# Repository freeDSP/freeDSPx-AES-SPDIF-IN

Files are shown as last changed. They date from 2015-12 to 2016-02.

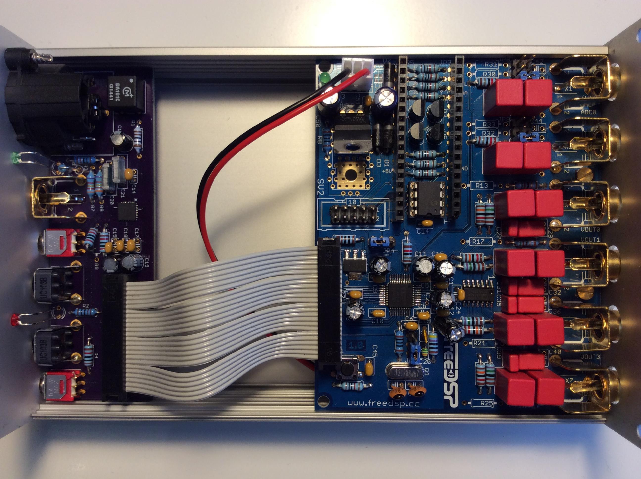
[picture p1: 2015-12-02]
DOCUMENTATION/PICTURES/Assembled V1.1.jpg

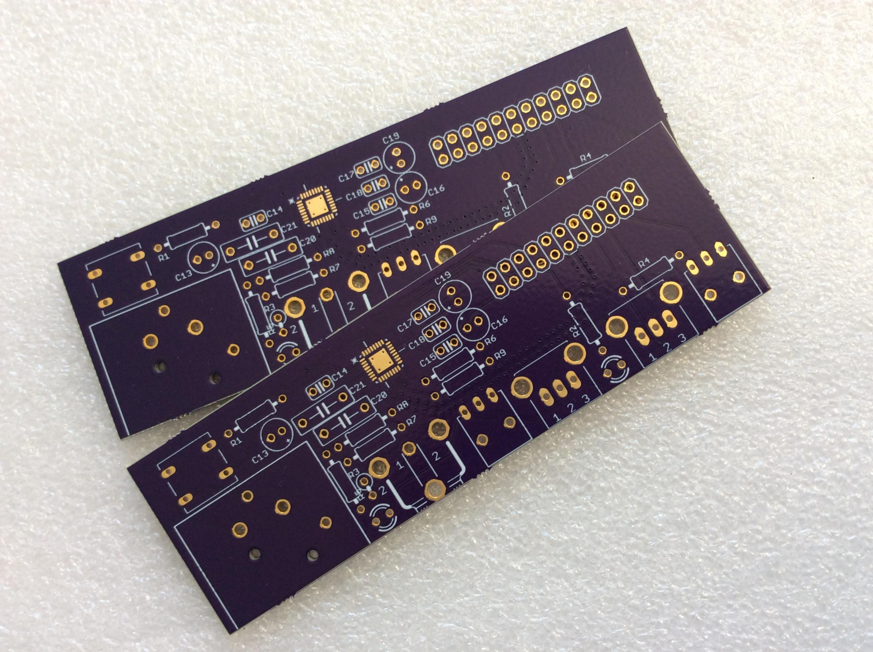
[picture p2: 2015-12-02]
DOCUMENTATION/PICTURES/PCBs V1.1.jpg

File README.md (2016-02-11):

# freeDSPx AES/SPDIF IN

BOARD STATUS: READY TO BE BUILT

MAIN COORDINATOR: [florian](https://github.com/FlorianPfeil)

This is a digital input add-on board based on a design found at [latent laboratories](http://www.latentlaboratories.com/dsp-01/). It's built around a CS8422 asynchronous sample rate converter, has S/PDIF and AES/EBU input plus two potentiometers, a toggle switch and a LED connected to the ADAU's GPIOs.

## Comments

* The design uses the bit clock signal of the serial output as master clock for the ASRC. Therefore, the output needs to be configured in SigmaStudio as ‚Master Mode‘. The BCLK frequency needs to be selected as ‚internal clock/4‘.

## License

This work and all other materials under https://github.com/freeDSP are licensed under a <a rel="license" href="http://creativecommons.org/licenses/by-sa/4.0/legalcode">Creative Commons Attribution Share-Alike 4.0 license</a>. This allows for both personal and commercial derivative works, as long as they credit freeDSP and release their designs under the same license.

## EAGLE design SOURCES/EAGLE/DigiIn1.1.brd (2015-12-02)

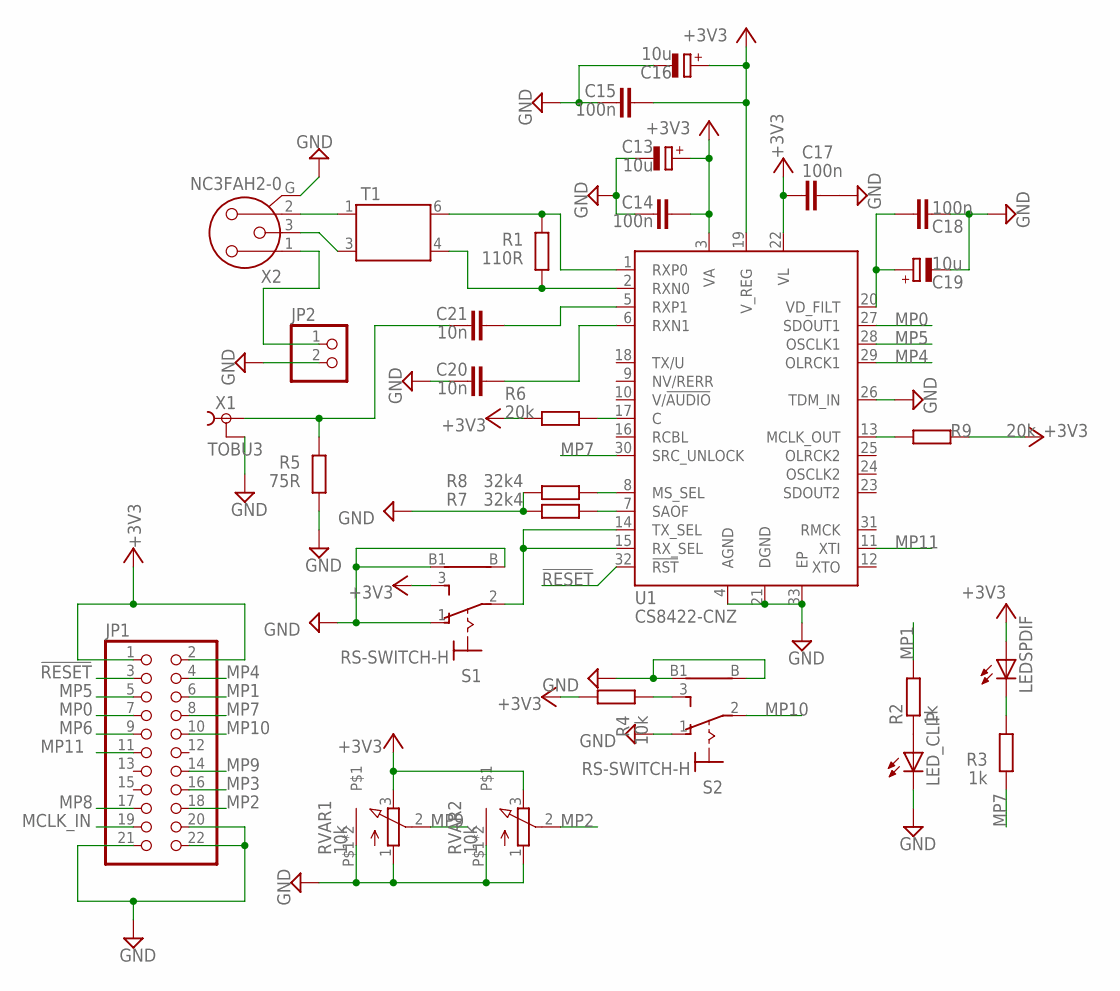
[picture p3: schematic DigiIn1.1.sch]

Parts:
C13, C16, C19: 10u; E2-5
C14, C15, C17, C18: 100n; C025-024X044
C20, C21: 10n; C075-032X103
JP1: PINHD-2X11; 2X11
JP2: PINHD-1X2; 1X02
LEDSPDIF: LED3MM
LED_CLIP: LED3MM
R1: 110R; 0207/10
R2, R3: 1k; 0207/10
R4: 10k; 0207/10
R5: 75R; 0207/2V
R6, R9: 20k; 0207/10
R7, R8: 32k4; 0207/10
RVAR1, RVAR2: 10k; ALPS-RK09
S1, S2: RS-SWITCH-H
T1: TRAFO_DIL6
U1: CS8422-CNZ; QFN50P500X500X100-33N
X1: TOBU3
X2: NC3FAH2-0

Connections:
!RESET!: JP1.3, U1.32 (!RST!)
+3V3: C13.+, C14.1, C15.1, C16.+, C17.1, JP1.1, JP1.2, LEDSPDIF.A, R4.2, R6.1, R9.2, RVAR1.3, RVAR2.3, S1.3, U1.3 (VA), U1.19 (V_REG), U1.22 (VL)
GND: C13.-, C14.2, C15.2, C16.-, C17.2, C18.2, C19.-, C20.2, JP1.20, JP1.21, JP1.22, JP2.2, LED_CLIP.K (C), R5.2, R7.1, R8.1, RVAR1.1, RVAR1.P$1, RVAR1.P$2, RVAR2.1, RVAR2.P$1, RVAR2.P$2, S1.1, S1.B, S1.B1, S2.1, S2.B, S2.B1, U1.4 (AGND), U1.21 (DGND), U1.26 (TDM_IN), U1.33 (EP), X1.2, X1.2@1 (2), X1.2@2 (2), X2.G
MCLK_IN: JP1.19
MP0: JP1.7, U1.27 (SDOUT1)
MP1: JP1.6, R2.2
MP2: JP1.18, RVAR2.2
MP3: JP1.16
MP4: JP1.4, U1.29 (OLRCK1)
MP5: JP1.5, U1.28 (OSCLK1)
MP6: JP1.9
MP7: JP1.8, R3.1, U1.30 (SRC_UNLOCK)
MP8: JP1.17
MP9: JP1.14, RVAR1.2
MP10: JP1.10, S2.2
MP11: JP1.11, U1.11 (XTI)
unnamed: LED_CLIP.A, R2.1
unnamed: R1.1, T1.6, U1.1 (RXP0)
unnamed: C21.2, R5.1, X1.1
unnamed: LEDSPDIF.K (C), R3.2
unnamed: R1.2, T1.4, U1.2 (RXN0)
unnamed: T1.1, X2.2
unnamed: T1.3, X2.3
unnamed: S1.2, U1.14 (TX_SEL), U1.15 (RX_SEL)
unnamed: C18.1, C19.+, U1.20 (VD_FILT)
unnamed: R4.1, S2.3
unnamed: JP2.1, X2.1
unnamed: C20.1, U1.6 (RXN1)
unnamed: C21.1, U1.5 (RXP1)
unnamed: R6.2, U1.17 (C)
unnamed: R7.2, U1.7 (SAOF)
unnamed: R8.2, U1.8 (MS_SEL)
unnamed: R9.1, U1.13 (MCLK_OUT)

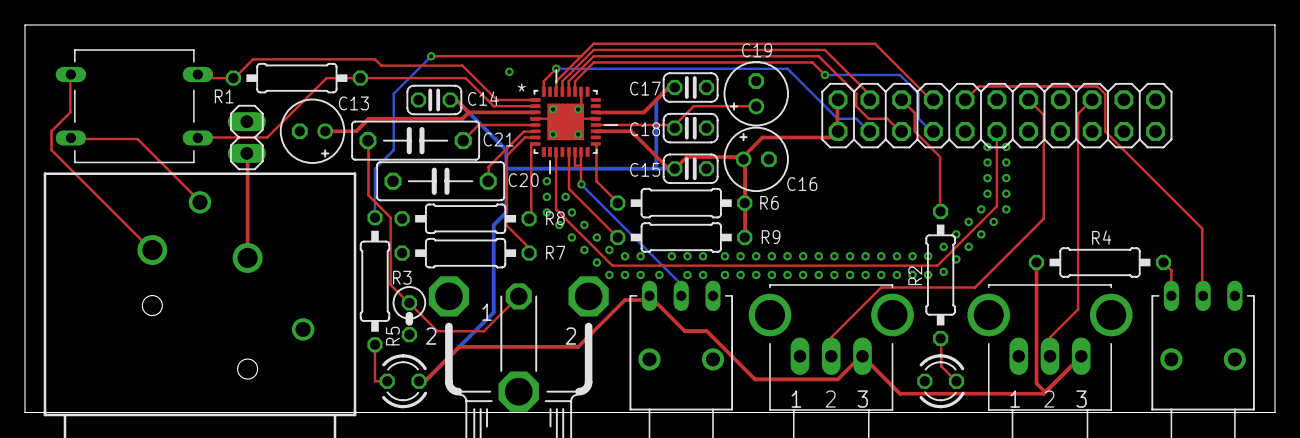
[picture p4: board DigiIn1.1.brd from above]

Board: 2 copper layers, 100.0 x 31.0 mm, 30 parts (0 on the bottom side), 29 nets.

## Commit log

2015-12-02 folder structure + initial sources V1.1
    added basic folder structure and files from Florian
    [DigiIn1.1.brd, DigiIn1.1.sch, freeDSP DigiIn Partlist.xls]
2015-12-02 added folders for gerber files
2016-01-18 2.1 XOver
    2.1 Crossover with master and sub volume, bypass switch and clip
    indicator
